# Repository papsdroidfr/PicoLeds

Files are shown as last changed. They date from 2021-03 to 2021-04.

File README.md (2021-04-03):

# PicoLeds
Lampe de chevet imprimée 3D aux ambiances lumineuses sympas: contrôle d'un anneau de 16 leds Neopixels RGB à l'aide d'un micro-contrôleur Raspberry [PICO](https://www.papsdroid.fr/post/hello-pico). 

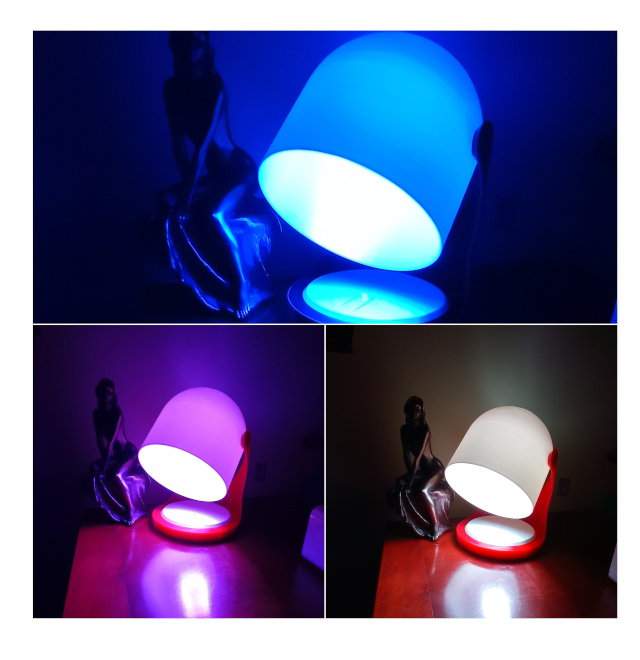
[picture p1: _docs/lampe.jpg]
lampe3D


## matériel nécessaire
* 1 Rapsberry PICO, avec les 2 rangées de pin headers soudées
* 1 anneau 16 leds RGB Neopixels
* 3 pin headers à souder sur l'anneau de leds
* 1 petit bouton poussoir 6mm
* 2 résistances 10k
* 3 pins header mâles qui seront soudés sur l'anneau de 16 leds afin d'y connecter des câbles dupond souples. (J'achète des rangées de 40 pins sécables)
* 6 câbles souples dupond pour relier l'anneau de leds: 3 femelle/femelle + 3 mâles/femelle, de couleur rouge, noir et blanc pour repérer les branchements. Prévoir du chatterton pour isoler les rallonges.
* 1 carte à faire fabriquer chez n'importe quel fabriquant de PCB à partir des fichiers GERBER disponibles sur le Github du projet.
* 1 connecteur coudés 3 pins à souder (2.54mm) 
* 1 alimentation 5V pour raspberry pi3 (avec un mini-usb donc) avec un bouton on/off intégré. Attention à ne pas prendre une alimentation pi4 usbC car ça n'est pas compatible pour alimenter le PICO (mini-usb).
* 1 manchon souple pour gainer les fils qui relient l'anneau de leds, diamètre 5-10mm.

## fritzing
Le prototype sur breadboard est simple à réaliser. Il faut souder les pin header 20 broches sur le PICO (ou acheter un PICO avec les pin header déjà soudés). 
J'ai aussi soudé 3 pin sur le ring Neopixel des 16 leds sur le +VCC, SIGNAL et GND afin de pouvoir le positionner sur la breadboard. 
Le bouton poussoir est monté en pull-up avec le jeux de 2 résistances 10k ohms.
Aucun filtrage "RC" n'est nécessaire avec le bouton poussoir car les faux-rebonds electro-mécaniques générés lors des appuis seront filtrés de manière logicielle.
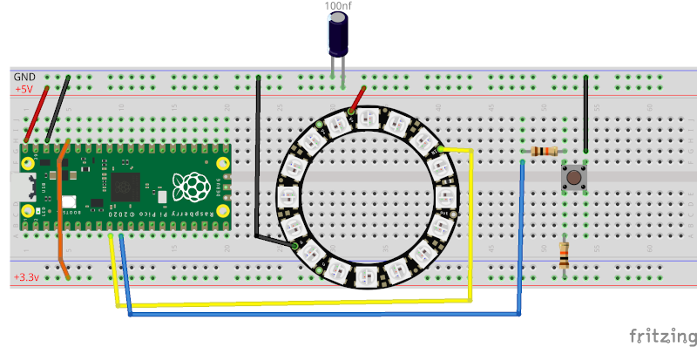
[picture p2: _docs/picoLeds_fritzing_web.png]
fritzing


### script MicroPython
Avant d'installer le script micoPython qui gère l'anneau Neopixel il faut d'abord configurer le Raspberry PICO en suivant [ce guide](https://www.papsdroid.fr/post/hello-pico).
Le script **main.py** dans le dossier /microPython est conçu à partir de l'exemple fourni par Raspberry concernant le [SDK microPython](https://datasheets.raspberrypi.org/pico/raspberry-pi-pico-python-sdk.pdf) sur le contrôle Neopixel.
Le bouton poussoir quand à lui est associé à une fonction callback appelée par interruption logicielle losque le Pin relié au bouton se retrouve à la masse (montage pull-up). Pour éviter les faux rebonds electro-mécaniques, la fonction callback commence par attendre un certain temps de stabilisation (50ms suffisent), 
puis elle contrôle que le bouton poussoir est toujours appuyé après ce laps de temps. 
Dans ce cas, on peut alors coder ce que doit exécuter cette fonction callback en étant sûr d'avoir évité tous les faux-rebonds.

Ce script commence par allumer les leds dans une ambiance douce orangée.
Chaque appui sur le bouton poussoir va provoquer un effet de "fade out" / "fade in" vers une nouvelle ambiance: doux -> vif(mode lecture) -> veilleuse violette -> veilleuse bleue.
La boucle d'événements (infinite loop) ne fait rien d'autre qu'éxécuter un time.sleep(0.5) qui est nécessaire pour ne pas saturer le processeur (curieusement ne rien faire en boucle infinie c'est le meilleur moyen de saturer un processeur qui va vite se retrouver en surchauffe).

### Circuit imprimé
les fichiers GERBER nécessaires à la création du circuit imprimé sont dans le dossier GERBER.
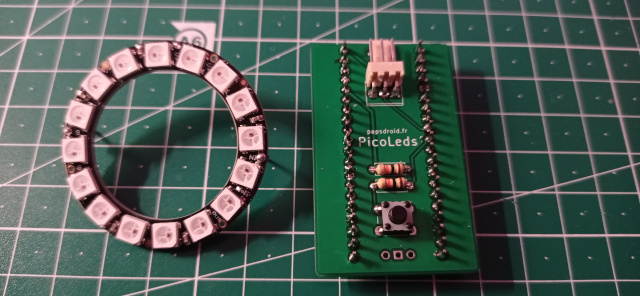
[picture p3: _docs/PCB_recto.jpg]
PCB_recto

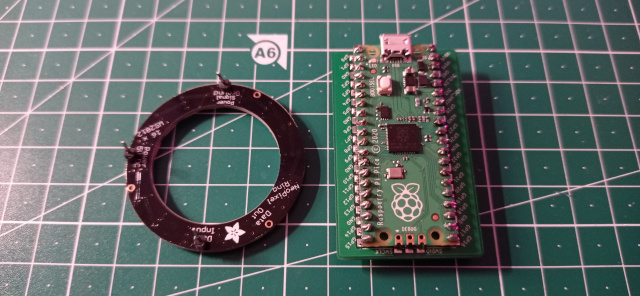
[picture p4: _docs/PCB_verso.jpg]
PCB_verso


Il faut commencer par souder au dessus les deux résistance, le bouton poussoir et le connecteur coudé pour y brancher l'anneau de leds.
En dessous il faut souder le PICO avec ses 2 rangées de pin header déjà soudées: ne pas se tromper de sens la sortie USB du PICO doit être dans le même sens que le connecteur 3 pins pour les leds. Relier l'anneau de leds en utilisant des cables souples dupont femelle/femelle: ne pas se tromper dans les connections +5v, GNG et SIGNAL(milieu) sinon l'anneau de leds ne survit pas.

## Impression 3D de la lampe
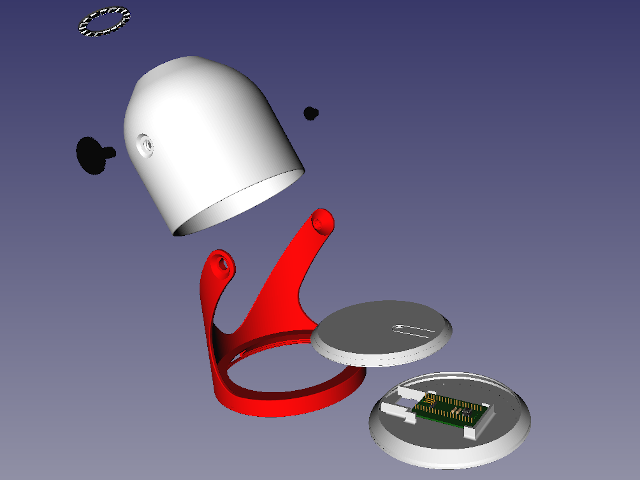
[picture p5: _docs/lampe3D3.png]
lampe3D


Cette lampe est une création originale de [DESKGROWN](https://cults3d.com/fr/mod%C3%A8le-3d/maison/minimal-bedside-lamp). J'ai modifié quelques éléments afin de pouvoir y loger l'électronique (carte logée dans le socle, passages pour les câbles, et rehausse de bouton poussoir sur le couvercle). Les fichiers STL sont disponibles dnas le dossier lamp3D_STL, il y a un fichier readme pour les consignes d'impression.

## assemblage de la lampe
Pour assembler la lampe suivez le guide de montage sur mon site: https://www.papsdroid.fr/post/picoleds

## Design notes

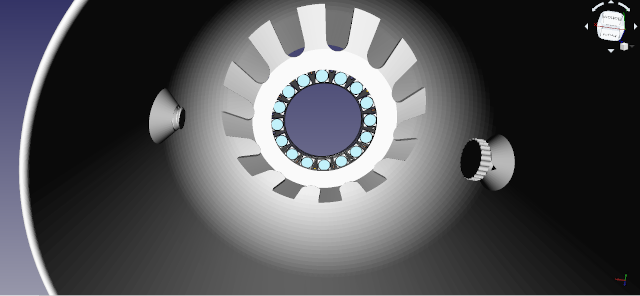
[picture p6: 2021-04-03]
_docs/lampe3D1.png

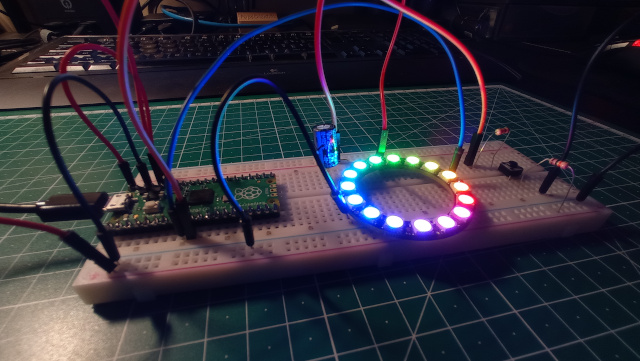
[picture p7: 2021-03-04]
_docs/IMG_20210304_190720_web.jpg

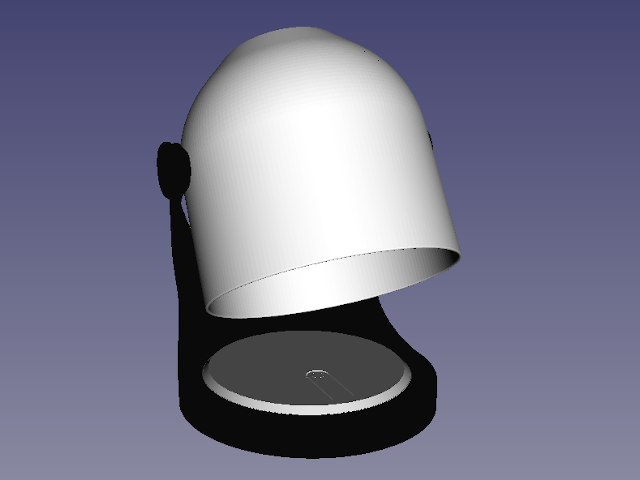
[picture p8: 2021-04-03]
_docs/lampe3D2.png

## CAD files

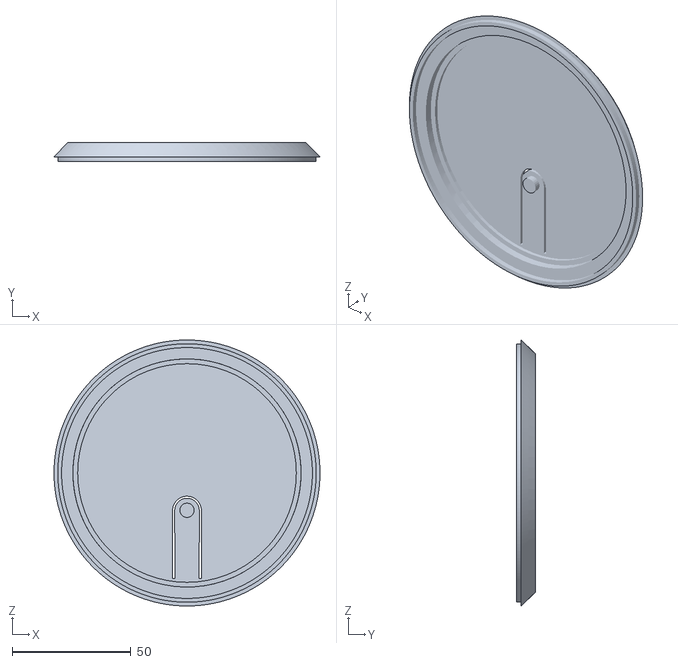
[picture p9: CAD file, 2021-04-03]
lampe3D_STL/couvercle_base.stl
111.9 x 8.00 x 111.9

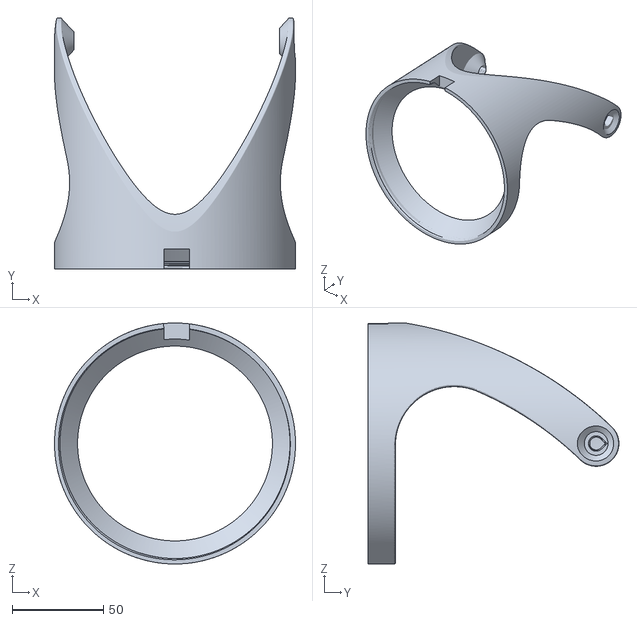
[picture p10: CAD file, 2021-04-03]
lampe3D_STL/base.stl
132.0 x 137.4 x 132.0

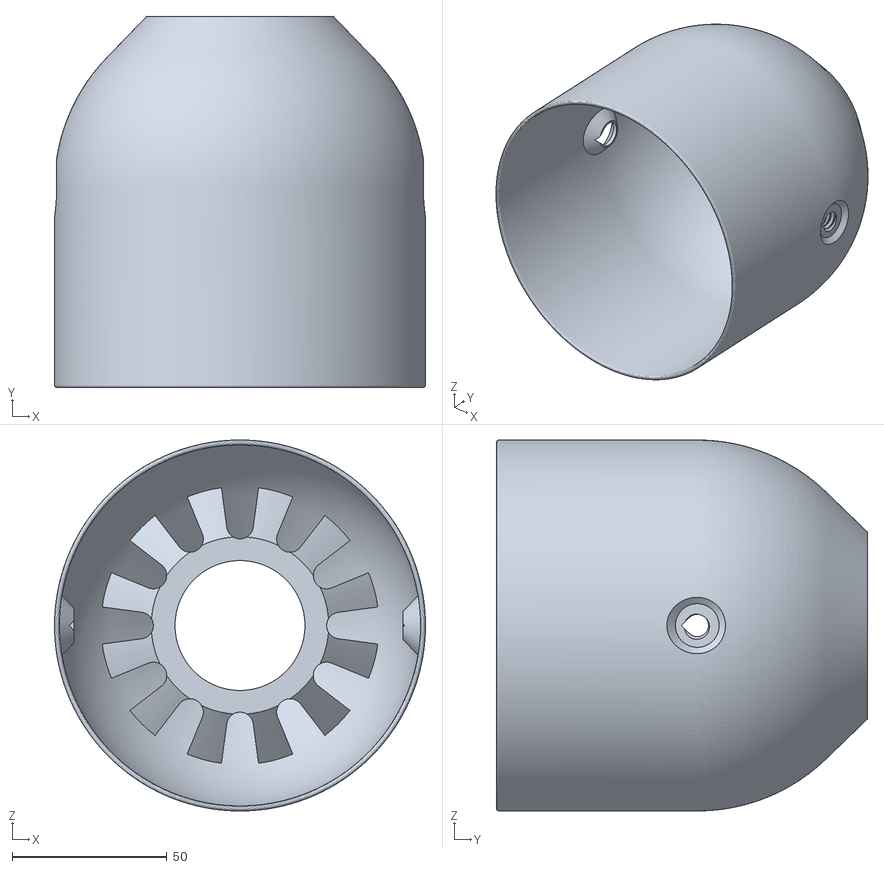
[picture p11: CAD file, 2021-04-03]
lampe3D_STL/Shade.stl
120.0 x 120.0 x 120.0

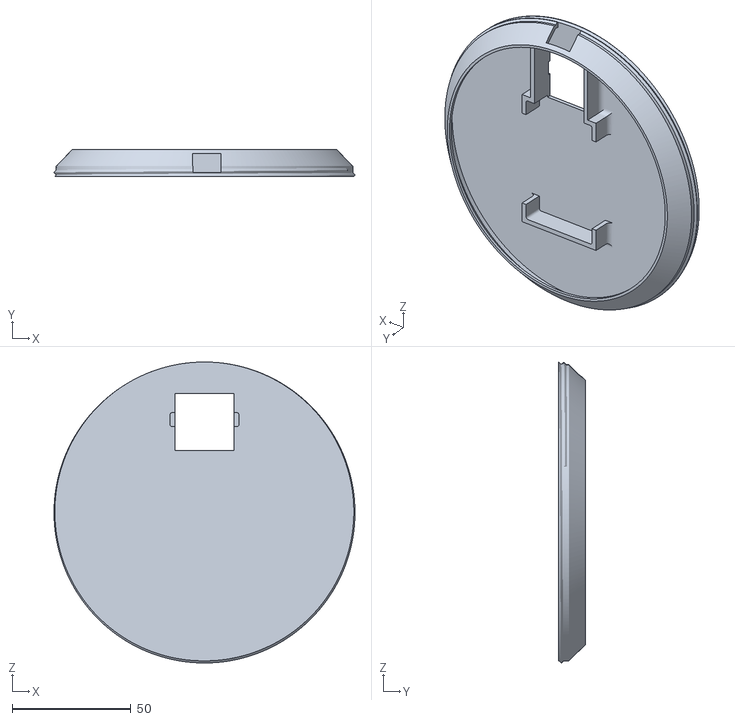
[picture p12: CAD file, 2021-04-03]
lampe3D_STL/fond.stl
126.6 x 11.3 x 126.6

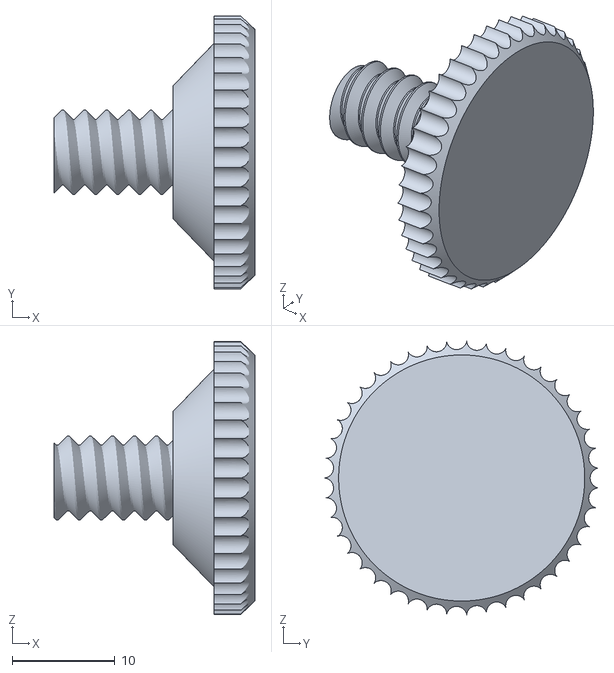
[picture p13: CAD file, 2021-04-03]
lampe3D_STL/Outer_Screw.stl
19.6 x 26.6 x 26.6

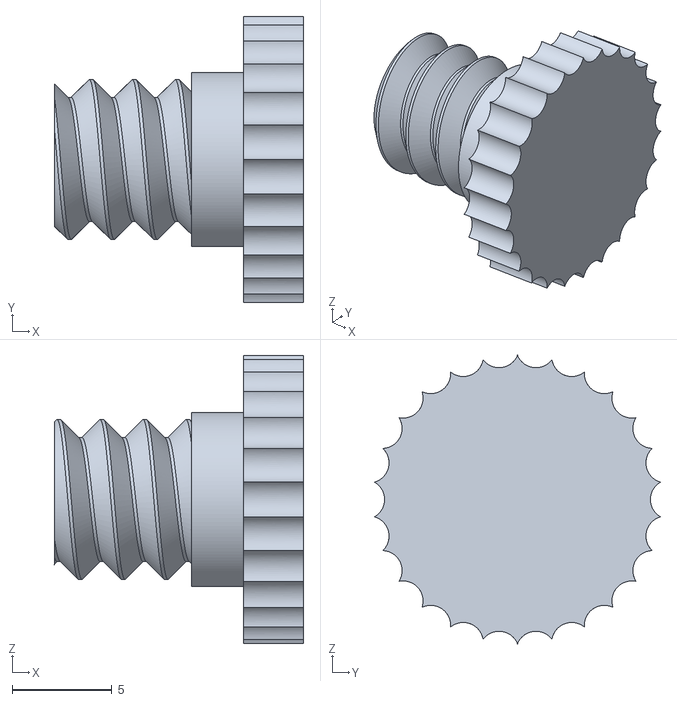
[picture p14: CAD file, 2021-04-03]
lampe3D_STL/Inner_Screw.stl
12.5 x 14.3 x 14.4

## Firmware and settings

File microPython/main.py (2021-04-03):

# runs on PICO

import array, time, rp2
from machine import Pin

@rp2.asm_pio(sideset_init=rp2.PIO.OUT_LOW, out_shiftdir=rp2.PIO.SHIFT_LEFT, autopull=True, pull_thresh=24)
def ws2812():
    T1 = 2
    T2 = 5
    T3 = 3
    wrap_target()
    label("bitloop")
    out(x, 1)               .side(0)    [T3 - 1]
    jmp(not_x, "do_zero")   .side(1)    [T1 - 1]
    jmp("bitloop")          .side(1)    [T2 - 1]
    label("do_zero")
    nop()                   .side(0)    [T2 - 1]
    wrap()

class LedsRGBws2812:
    ''' Neopixel RGB WS2812 Class
        instance: leds = LedsRGBws2812() or LedsRGBws2812(n_leds, pin_num, brightness)
    '''

    def __init__(self, n_leds=16, pin_num=6, brightness=0.2):
        ''' constructor: Configure the WS2812 LEDs. '''
        
        print('init leds RGB')
        self.NUM_LEDS = n_leds
        self.PIN_NUM = pin_num
        self.brightness = brightness
        self.BLACK = (0, 0, 0)
        self.RED = (255, 0, 0)
        self.YELLOW = (255, 150, 0)
        self.ORANGE = (255, 139, 0)
        self.GREEN = (0, 255, 0)
        self.CYAN = (0, 255, 255)
        #self.BLUE = (0, 0, 255)
        self.BLUE = (0, 0, 127)
        #self.PURPLE = (180, 0, 255)
        self.PURPLE = (90, 0, 127)
        self.WHITE = (255, 255, 255)
        #self.WARM = (255, 200, 100)
        self.WARM = (255, 140 , 40)
        self.MORNING = (127,70,10)
        self.COLORS = (self.MORNING, self.WARM, self.PURPLE, self.BLUE)

    
        # Create the StateMachine with the ws2812 program, outputting on pin
        self.sm = rp2.StateMachine(0, ws2812, freq=8_000_000, sideset_base=Pin(self.PIN_NUM))

        # Start the StateMachine, it will wait for data on its FIFO.
        self.sm.active(1)

        # Display a pattern on the LEDs via an array of LED RGB values.
        self.ar = array.array("I", [0 for _ in range(self.NUM_LEDS)])


    def pixels_show(self):
        ''' add data into sm FIFO: show de pixels '''
        dimmer_ar = array.array("I", [0 for _ in range(self.NUM_LEDS)])
        for i,c in enumerate(self.ar):
            r = int(((c >> 8) & 0xFF) * self.brightness)
            g = int(((c >> 16) & 0xFF) * self.brightness)
            b = int((c & 0xFF) * self.brightness)
            dimmer_ar[i] = (g<<16) + (r<<8) + b
        self.sm.put(dimmer_ar, 8)
        time.sleep_ms(10)

    def pixels_set(self, i, color):
        ''' set pixel number i with color=(r,g,b) '''
        self.ar[i] = (color[1]<<16) + (color[0]<<8) + color[2]

    def pixels_fill(self, color):
        ''' set all pixels with same color (r,g,b) '''
        for i in range(len(self.ar)):
            self.pixels_set(i, color)

    def pixels_off(self):
        self.pixels_fill(self.BLACK)
        self.pixels_show()
        
    def color_chase(self, color, wait):
        ''' color(r,g,b) grow from pixel 0 to the end.'''
        for i in range(self.NUM_LEDS):
            self.pixels_set(i, color)
            time.sleep(wait)
            self.pixels_show()
        time.sleep(0.2)
 
    def wheel(self, pos):
        ''' Input a value 0 to 255 to get a color value (r,g,b).
            The colours are a transition r - g - b - back to r.
        '''
        if pos < 0 or pos > 255:
            return (0, 0, 0)
        if pos < 85:
            return (255 - pos * 3, pos * 3, 0)
        if pos < 170:
            pos -= 85
            return (0, 255 - pos * 3, pos * 3)
        pos -= 170
        return (pos * 3, 0, 255 - pos * 3)
 
 
    def rainbow_cycle(self, wait=0):
        ''' move colors in a rainbow cycle '''
        for j in range(255):
            for i in range(self.NUM_LEDS):
                rc_index = (i * 256 // self.NUM_LEDS) + j
                self.pixels_set(i, self.wheel(rc_index & 255))
            self.pixels_show()
            time.sleep(wait)
    
    def fade_out(self, n_steps, color, wait):
        ''' fade out color(r,g,b) to BLACK in n_steps   '''
        r_delta, g_delta, b_delta = color[0]//n_steps, color[1]//n_steps, color[2]//n_steps
        for j in range(n_steps):
            self.pixels_fill( (color[0]-j*r_delta , color[1]-j*g_delta , color[2]-j*b_delta) )
            self.pixels_show()
            time.sleep(wait)
        self.pixels_off()
        time.sleep(wait)

    def fade_in(self, n_steps, color, wait):
        ''' fade in from BLACK to color(r,g,b) in n_steps   '''
        r_delta, g_delta, b_delta = color[0]//n_steps, color[1]//n_steps, color[2]//n_steps
        for j in range(n_steps, 0, -1 ):
            self.pixels_fill( (color[0]-j*r_delta , color[1]-j*g_delta , color[2]-j*b_delta) )
            self.pixels_show()
            time.sleep(wait)
        time.sleep(wait)


class Application:
    
    def __init__(self):
        ''' initialize leds RGB and push Button'''
        self.leds = LedsRGBws2812(brightness=1)
        self.button = Pin(7, Pin.IN, Pin.PULL_UP)
        #self.leds.rainbow_cycle()
        self.id_color=0
        self.leds.fade_in(10, self.leds.COLORS[0], 0.05)
        #callback function called with push button
        self.button.irq(self.callback, Pin.IRQ_FALLING)
        self.loop()  #inifinite loop of events 
        
    
    def callback(self, pin):
        ''' callback function called when buton is pushed '''
        time.sleep(0.05) # wait 50ms : stabilization to avoid rebounds.
        if not(self.button.value()): # buton still pressed after the stabilization period ?
            #print('button pressed', pin.irq().flags())
            self.leds.fade_out(10, self.leds.COLORS[self.id_color], 0.05)
            self.id_color = (self.id_color+1) % (len(self.leds.COLORS)) 
            #self.leds.color_chase(self.leds.COLORS[self.id_color], 0.05)
            self.leds.fade_in(10, self.leds.COLORS[self.id_color], 0.05)
            
    
    def loop(self):
        while(True):
            time.sleep(0.2)


appl=Application()

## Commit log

2021-03-22 PCB Gerber Files
2021-04-03 3D printing STL files
    [Inner_Screw.stl, Outer_Screw.stl, Shade.stl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]
